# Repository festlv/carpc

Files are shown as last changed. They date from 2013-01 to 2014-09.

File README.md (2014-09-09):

RaspberryPi based CarPC.
===========================

This repository hosts firmware and software for my RaspberryPi based CarPC
build.

* **avr-firmware/** contains firmware which is running on Atmega 328p
  microcontroller. It requires avr-gcc, avr-binutils and scons.
  Sample usage:

     ```scons upload```

  Flashes the microcontroller (assumes usbasp programmer connected).

* **linux_software/** folder contains userspace driver which passes keypresses
  from serial port to uinput. Requires python2.7, pyserial and evdev
  Sample usage:
  ```bash
     virtualenv .env
     source .env/bin/activate
     pip install -r requirements.txt
     python driver.py /dev/ttyAMA0
    ```
   Runs the input driver which expects that microcontroller is connected to
   /dev/ttyAMA0 (serial port on RasPi).

* **hardware/** contains schematics and PCB layout drawn in KiCad.

For more information, please see: http://wot.lv/category/rpi-carpc.html

```
------------------------------------------------------------------------------
Copyright (c) 2013 Reinis Veips. 

All rights reserved.

Redistribution and use in source and binary forms, with or without
modification, are permitted provided that the following conditions are met:

  1. Redistributions of source code must retain the above copyright notice,
     this list of conditions and the following disclaimer.

  2. Redistributions in binary form must reproduce the above copyright 
     notice, this list of conditions and the following disclaimer in 
     the documentation and/or other materials provided with the distribution.

  3. The names of the authors may not be used to endorse or promote products
     derived from this software without specific prior written permission.

THIS SOFTWARE IS PROVIDED ``AS IS'' AND ANY EXPRESSED OR IMPLIED WARRANTIES,
INCLUDING, BUT NOT LIMITED TO, THE IMPLIED WARRANTIES OF MERCHANTABILITY AND
FITNESS FOR A PARTICULAR PURPOSE ARE DISCLAIMED. IN NO EVENT SHALL JCRAFT,
INC. OR ANY CONTRIBUTORS TO THIS SOFTWARE BE LIABLE FOR ANY DIRECT, INDIRECT,
INCIDENTAL, SPECIAL, EXEMPLARY, OR CONSEQUENTIAL DAMAGES (INCLUDING, BUT NOT
LIMITED TO, PROCUREMENT OF SUBSTITUTE GOODS OR SERVICES; LOSS OF USE, DATA,
OR PROFITS; OR BUSINESS INTERRUPTION) HOWEVER CAUSED AND ON ANY THEORY OF
LIABILITY, WHETHER IN CONTRACT, STRICT LIABILITY, OR TORT (INCLUDING
NEGLIGENCE OR OTHERWISE) ARISING IN ANY WAY OUT OF THE USE OF THIS SOFTWARE,
EVEN IF ADVISED OF THE POSSIBILITY OF SUCH DAMAGE.
```

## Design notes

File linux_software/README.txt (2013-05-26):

At startup, launch driver/driver.py in background.
> python driver/driver.py &

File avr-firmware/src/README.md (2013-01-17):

# Uploading code #

Code can built and uploaded using `scons upload`.
Other supported scons targets are:
`scons read-fuses`
`scons write-fuses`

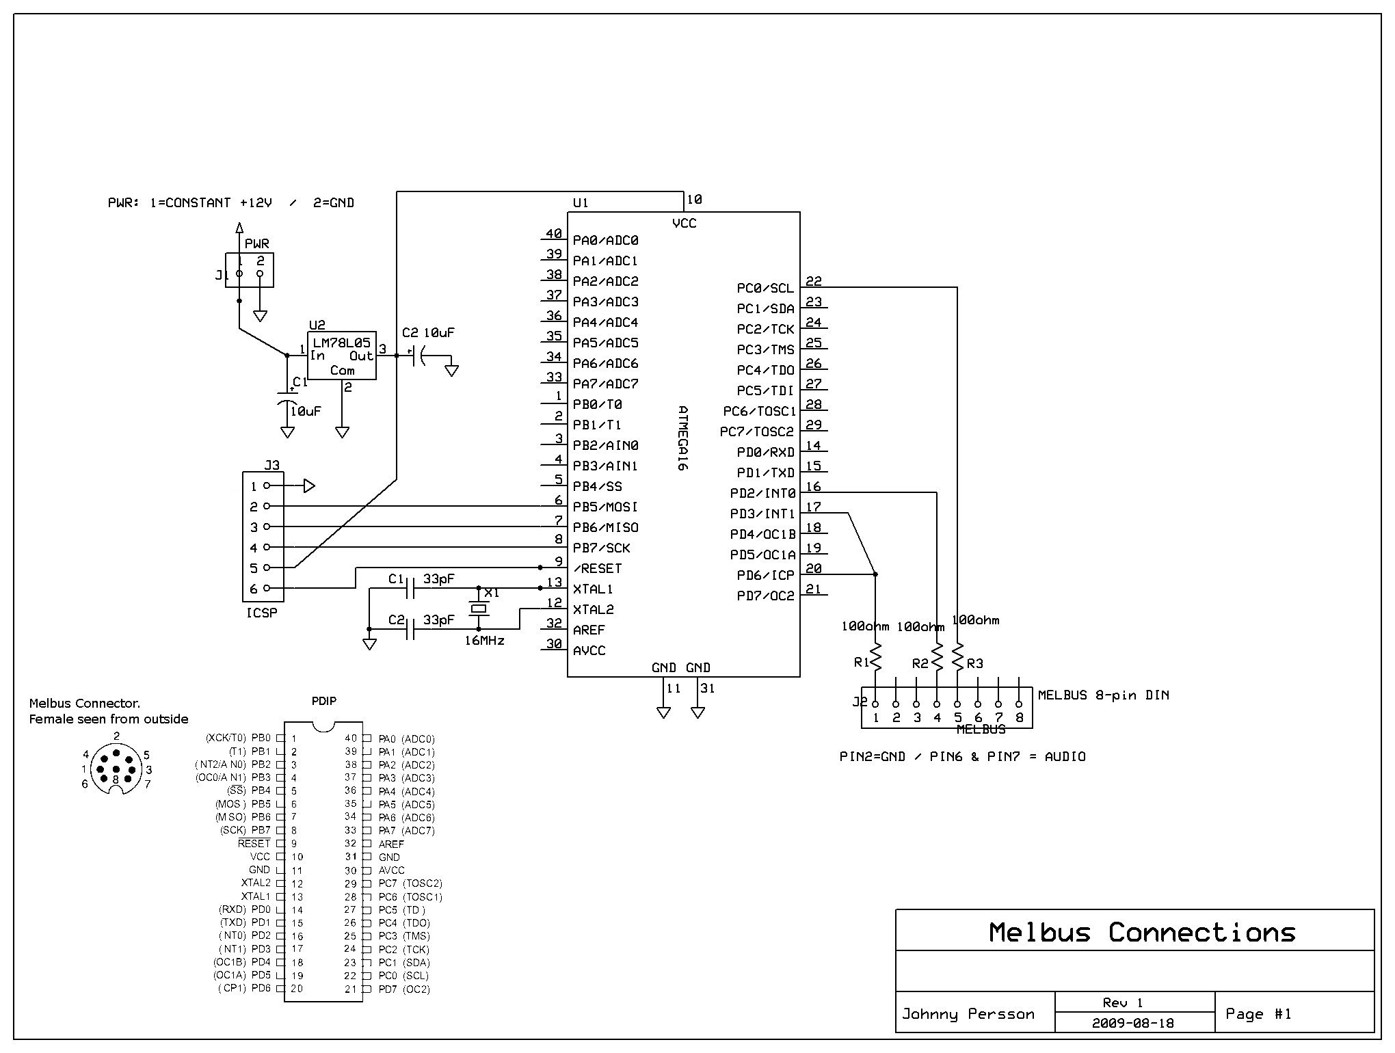
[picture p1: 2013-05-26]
doc/melbus-schematic.jpg

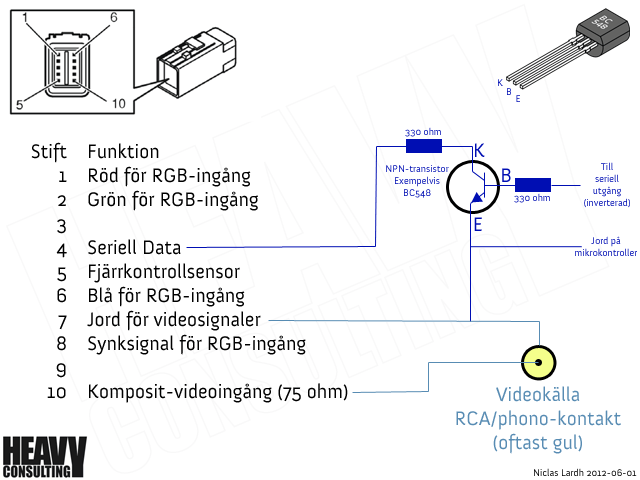
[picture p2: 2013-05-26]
doc/screen_connection.png

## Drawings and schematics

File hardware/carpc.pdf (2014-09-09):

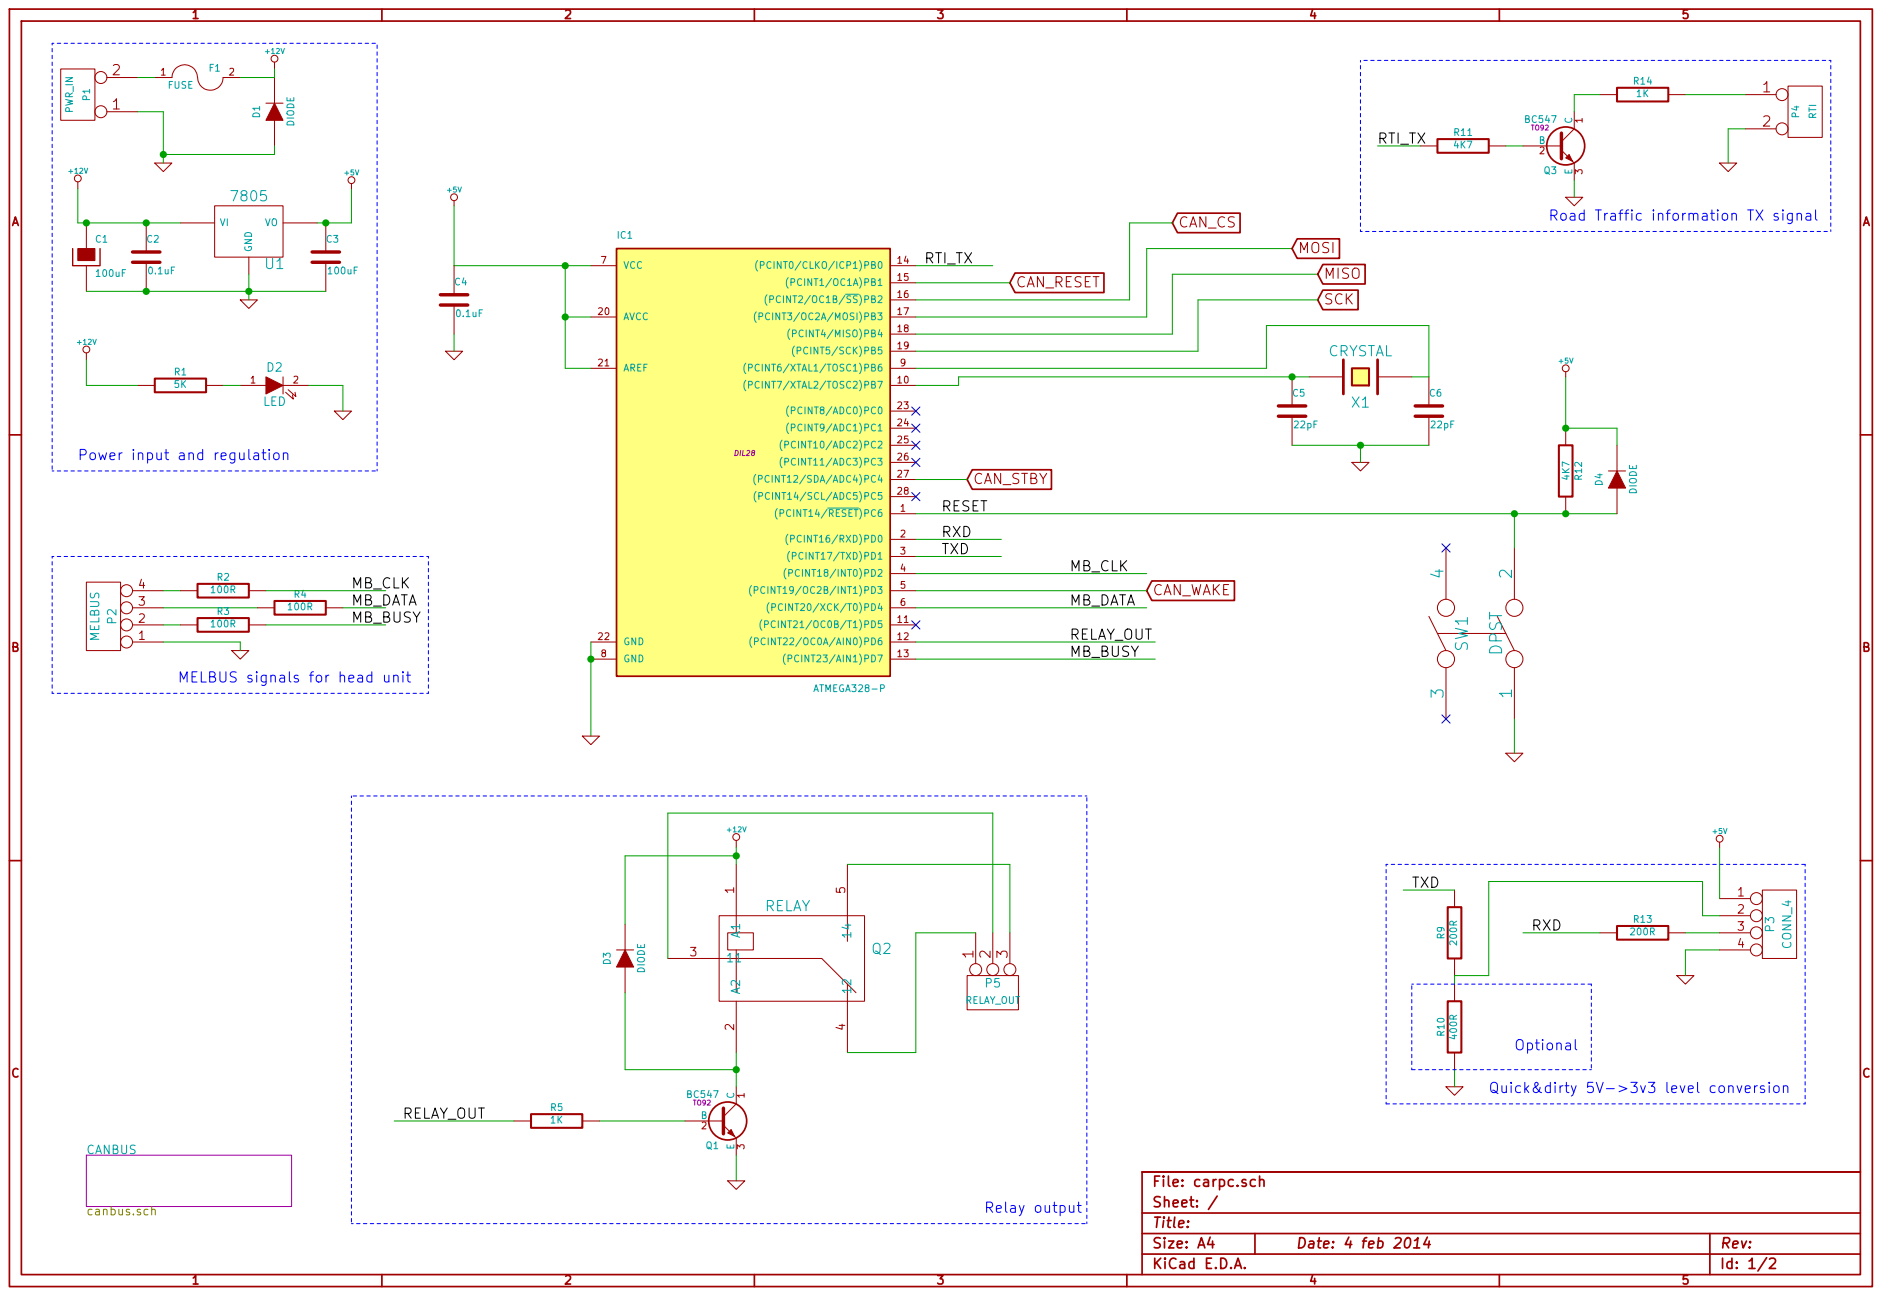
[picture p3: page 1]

+12V Power input and regulation

Road Traffic information TX signal 1

Id: 1/2 Title: File: carpc.sch
Sheet: /

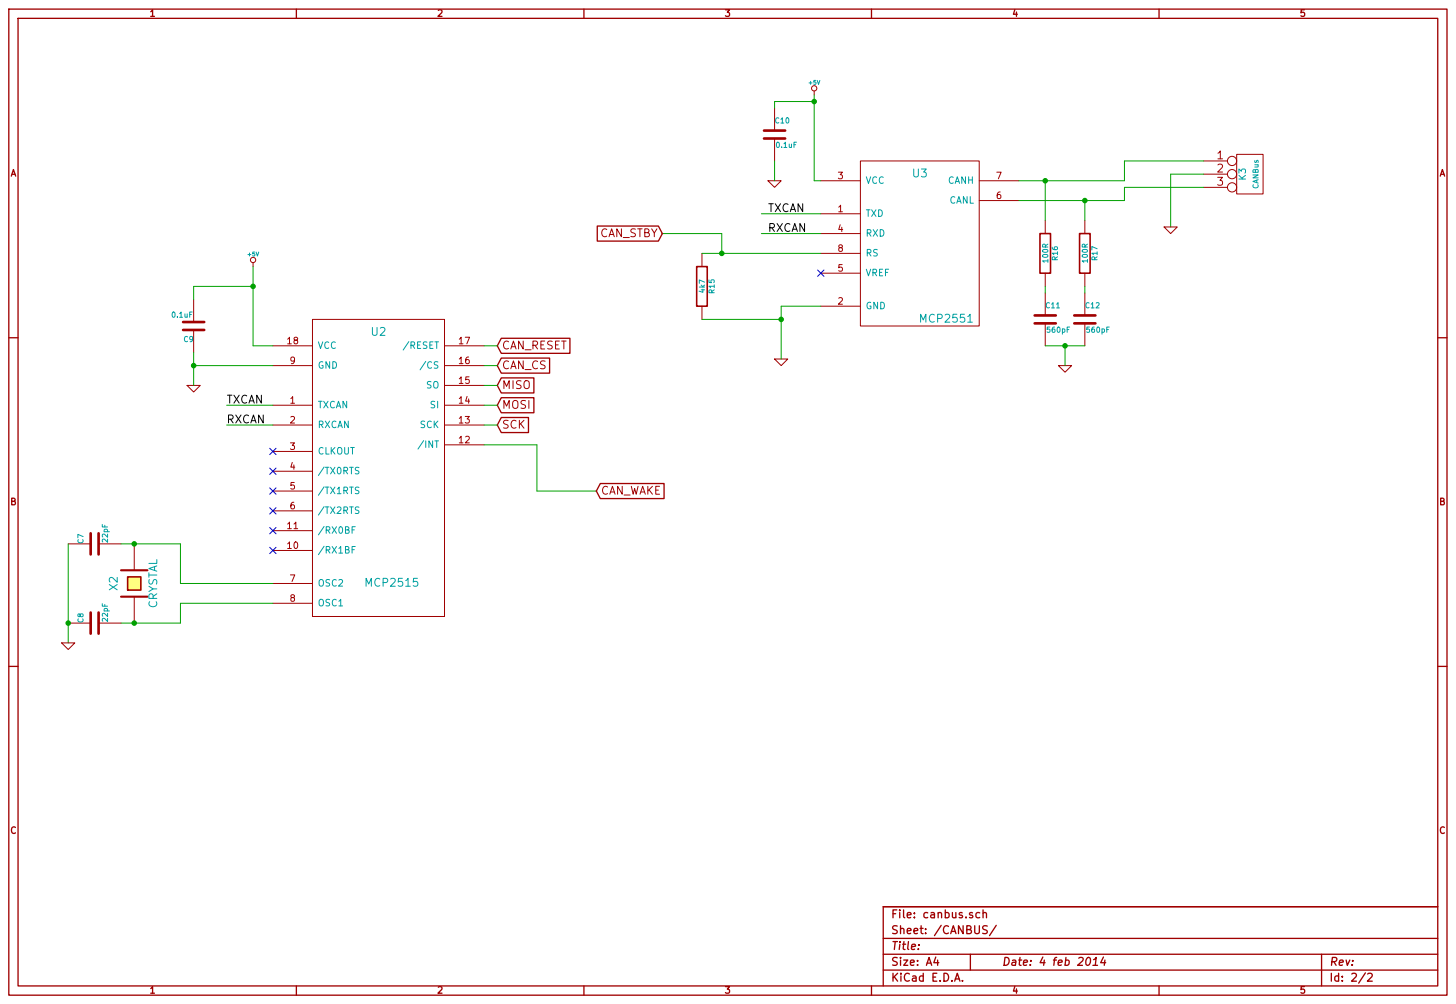
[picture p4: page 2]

Id: 2/2 Title: File: canbus.sch Sheet: /CANBUS/

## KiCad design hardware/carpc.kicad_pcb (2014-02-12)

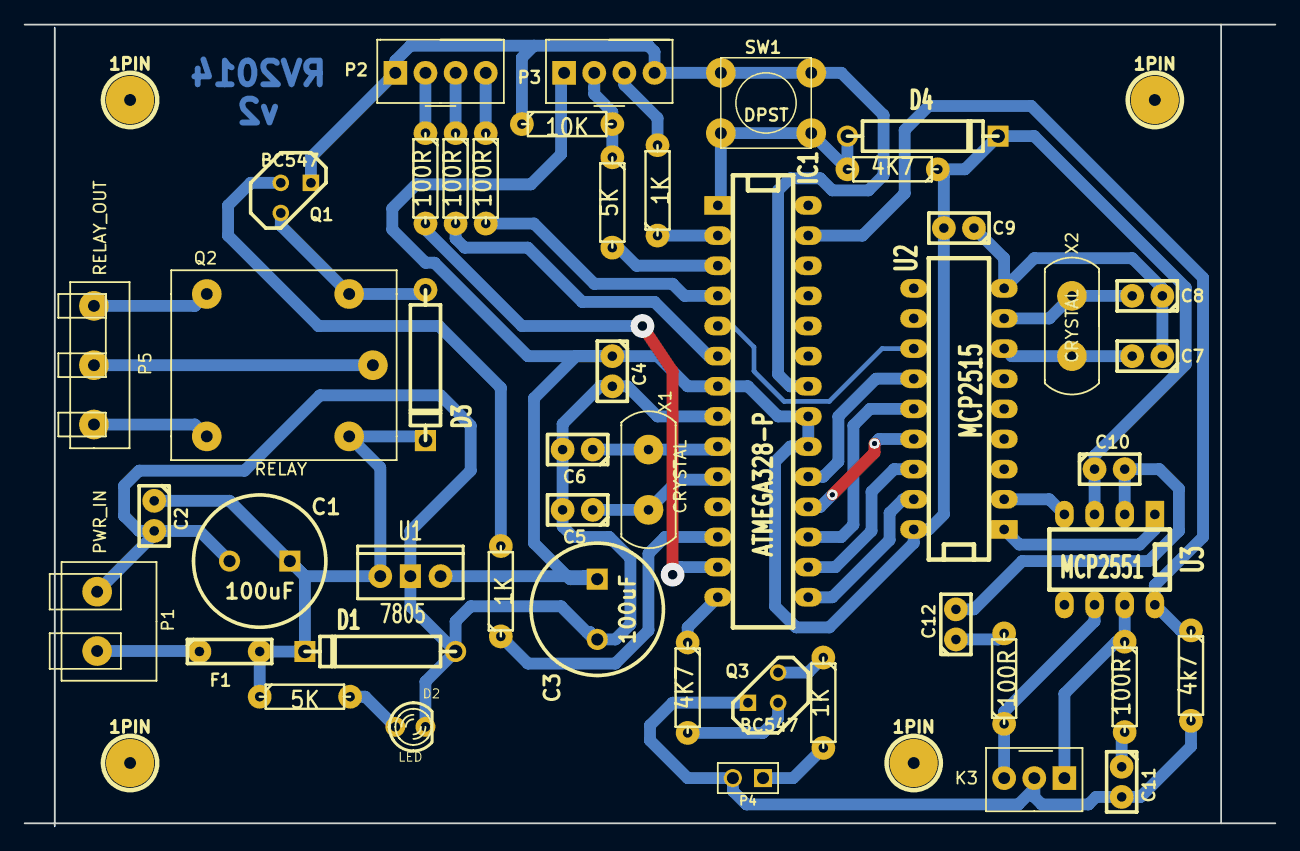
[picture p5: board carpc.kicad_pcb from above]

Board: 2 copper layers, 105.4 x 67.6 mm, 51 parts (0 on the bottom side), 43 nets.

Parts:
1PIN, 1PIN#2, 1PIN#3, 1PIN#4: P***; 1pin
C1, C3: 100uF; C2V10
C2, C4, C9, C10: 0.1uF; C1
C5, C6, C7, C8: 22pF; C1
C11, C12: 560pF; C1
D1, D3, D4: DIODE; D5
D2: LED; LED-3MM
F1: FUSE; C2
IC1: ATMEGA328-P; DIP-28__300_ELL
K3: CANBus; PIN_ARRAY_3X1
P1: PWR_IN; SCREW_TERM_2
P2: MELBUS; PIN_ARRAY_4x1
P3: CONN_4; PIN_ARRAY_4x1
P4: RTI; PIN_ARRAY_2X1
P5: RELAY_OUT; SCREW_TERM_3
Q1, Q3: BC547; TO92-EBC
Q2: RELAY; FINDER_RELAY
R1, R9: 5K; R3
R2, R3, R4, R16, R17: 100R; R3
R5, R13, R14: 1K; R3
R10: 10K; R3
R11, R12: 4K7; R3
R15: 4k7; R3
SW1: DPST; SW_PUSH_SMALL
U1: 7805; LM78XXV
U2: MCP2515; DIP-18__300_ELL
U3: MCP2551; DIP-8__300_ELL
X1, X2: CRYSTAL; XTAL

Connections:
+5V: C3.1, C4.1, C9.2, C10.1, D4.2, IC1.7, IC1.20, IC1.21, P3.1, R12.1, U1.VO, U2.18, U3.3
+12V: C1.1, C2.1, D1.2, D3.2, F1.2, Q2.1, R1.1, U1.VI
/CANBUS/RXCAN: U2.2, U3.4
/CANBUS/TXCAN: U2.1, U3.1
/MB_BUSY: IC1.13, R3.2
/MB_CLK: IC1.4, R2.2
/MB_DATA: IC1.6, R4.2
/RELAY_OUT: IC1.12, R5.1
/RESET: D4.1, IC1.1, R12.2, SW1.2
/RTI_TX: IC1.14, R11.1
/RXD: IC1.2, R13.1
/TXD: IC1.3, R9.2
CAN_CS: IC1.16, U2.16
CAN_RESET: IC1.15, U2.17
CAN_STBY: IC1.27, R15.1, U3.8
CAN_WAKE: IC1.5, U2.12
GND: C1.2, C2.2, C3.2, C4.2, C5.2, C6.2, C7.1, C8.1, C9.1, C10.2, C11.2, C12.2, D1.1, D2.2, IC1.8, IC1.22, K3.2, P1.1, P2.1, P3.4, P4.2, Q1.E, Q3.E, R10.1, R15.2, SW1.1, U1.GND, U2.9, U3.2
MISO: IC1.18, U2.15
MOSI: IC1.17, U2.14
unnamed: P5.2, Q2.3
unnamed: D3.1, Q1.C, Q2.2
unnamed: P5.3, Q2.5
unnamed: P5.1, Q2.4
unnamed: F1.1, P1.2
unnamed: D2.1, R1.2
unnamed: P4.1, R14.2
unnamed: Q1.B, R5.2
unnamed: P3.2, R9.1, R10.2
unnamed: P3.3, R13.2
unnamed: P2.4, R2.1
unnamed: P2.2, R3.1
unnamed: P2.3, R4.1
unnamed: Q3.B, R11.2
unnamed: Q3.C, R14.1
unnamed: C6.1, IC1.9, X1.1
unnamed: C5.1, IC1.10, X1.2
unnamed: C12.1, R17.2
unnamed: C11.1, R16.2
unnamed: K3.1, R16.1, U3.7
unnamed: K3.3, R17.1, U3.6
unnamed: C8.2, U2.8, X2.1
unnamed: C7.2, U2.7, X2.2
SCK: IC1.19, U2.13

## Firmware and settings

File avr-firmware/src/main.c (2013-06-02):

#include <avr/io.h>
#include "config.h"

#include "can_volvo/can_volvo.h"
#include "canbus/canbus.h"
#include "uart/uart.h"
#include <stdio.h>
#include <util/delay.h>
#include "rti/rti.h"
#include "time/time.h"

uint8_t tmp;
char tempchar;
CAN_MESSAGE tx;
uint8_t *id_ptr;

int main(void) {
    uart_init();
    time_init();
    rti_init();
    can_volvo_init();
    printf("#Init done.\n\n");

    while (1) {
        rti_step();
        can_volvo_step();        
    }
}

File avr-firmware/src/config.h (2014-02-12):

#ifndef __CONFIG__H
#define __CONFIG__H


#include <avr/io.h>


#define RTI_SERIAL_TX_DDR DDRB
#define RTI_SERIAL_TX_PORT PORTB
#define RTI_SERIAL_TX_BIT PB0


#define CANBUS_RESET_DDR DDRB
#define CANBUS_RESET_PORT PORTB
#define CANBUS_RESET_BIT PB1

#define CANBUS_CS_DDR DDRB
#define CANBUS_CS_PORT PORTB
#define CANBUS_CS_BIT PB2

#define RELAY_DDR DDRD
#define RELAY_PORT PORTD
#define RELAY_BIT PD6

//define this to receive CANBUS data via serial console
//#define CANBUS_LOGGING_MODE 1

#endif

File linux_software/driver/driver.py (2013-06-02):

import argparse
import time
from button_map import BUTTONS
from serial_reader import SerialReader
from serial_uinput import Input
from Queue import Queue, Empty


def main():
    parser = argparse.ArgumentParser()
    parser.add_argument("port", help="Serial port to listen for events.")
    args = parser.parse_args()
    inp = Input()
    time.sleep(5)
    q = Queue()
    s = SerialReader(args.port, q)
    s.start()

    while True:
        try:
            item = q.get(block=False)
            keycode = BUTTONS.get(item[0], False)
            if keycode:
                inp.inject_event(keycode, item[1])
        except Empty:
            pass
        except KeyboardInterrupt:
            break

    s.stop()

if __name__ == '__main__':
    main()

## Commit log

2013-01-20 SPI now sort of works
2013-03-27 Updated RTI code, added timer
2013-03-30 Fixed before testing in car
    [canbus.c, main.c]
2013-03-31 Button reading now works
2013-04-02 Added rev1 of schematics
2013-05-21 Added input driver which reads keycodes from serial port and injects them in evdev using uinput
2013-05-26 Updated firmware to start relay
2013-05-27 CAN id and data were completely wrong
    [main.c]
2013-05-28 Fixed button reading code
    [config.h, main.c, serial_reader.py]
2013-06-02 Implemented power managment for RasPi
2013-06-03 Added description for brightness message in canbus
2014-01-21 Started fresh version of hardware
    [canbus.sch, carpc.sch]
2014-01-22 Initial DIP version almost ready- needs verification and review
    [canbus.sch, carpc.kicad_pcb, carpc.sch]
2014-01-24 Finished PCB layout
    [canbus.sch, carpc.kicad_pcb, carpc.sch]
2014-01-24 Moved references to be out of the way of parts
    [carpc.kicad_pcb]
2014-01-24 Increased via sizes
    [carpc.kicad_pcb]
2014-01-26 Moved via further from MCU
    [carpc.kicad_pcb]
2014-02-04 Fixed an error with transistor pinout (it can be fixed easily by swapping both TO-92 transistors
    [canbus.sch, carpc.kicad_pcb, carpc.sch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]
2014-05-02 Added PDF version of schematics
2014-09-09 Updated schematics
